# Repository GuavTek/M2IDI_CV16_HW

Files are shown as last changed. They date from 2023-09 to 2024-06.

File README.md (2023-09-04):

This eurorack module has 16 general purpose outputs which can be used for: CV, gates, envelopes, LFOs+++. 
View this project on [CADLAB.io](https://cadlab.io/project/25235) to see renders of schematics and PCBs, as well as current issues. 

<h2> A part of the M2IDI prototypes </h2>

<p>
The code for this module can be found on  
<a href="https://github.com/GuavTek/M2IDI_CV16">
			  GitHub
		  </a>
</p>

<p> 
More info on the M2IDI system can be found on the 
<a href="https://hackaday.io/project/182092-modular-midi">
			  Hackaday project page
		  </a>

</p>

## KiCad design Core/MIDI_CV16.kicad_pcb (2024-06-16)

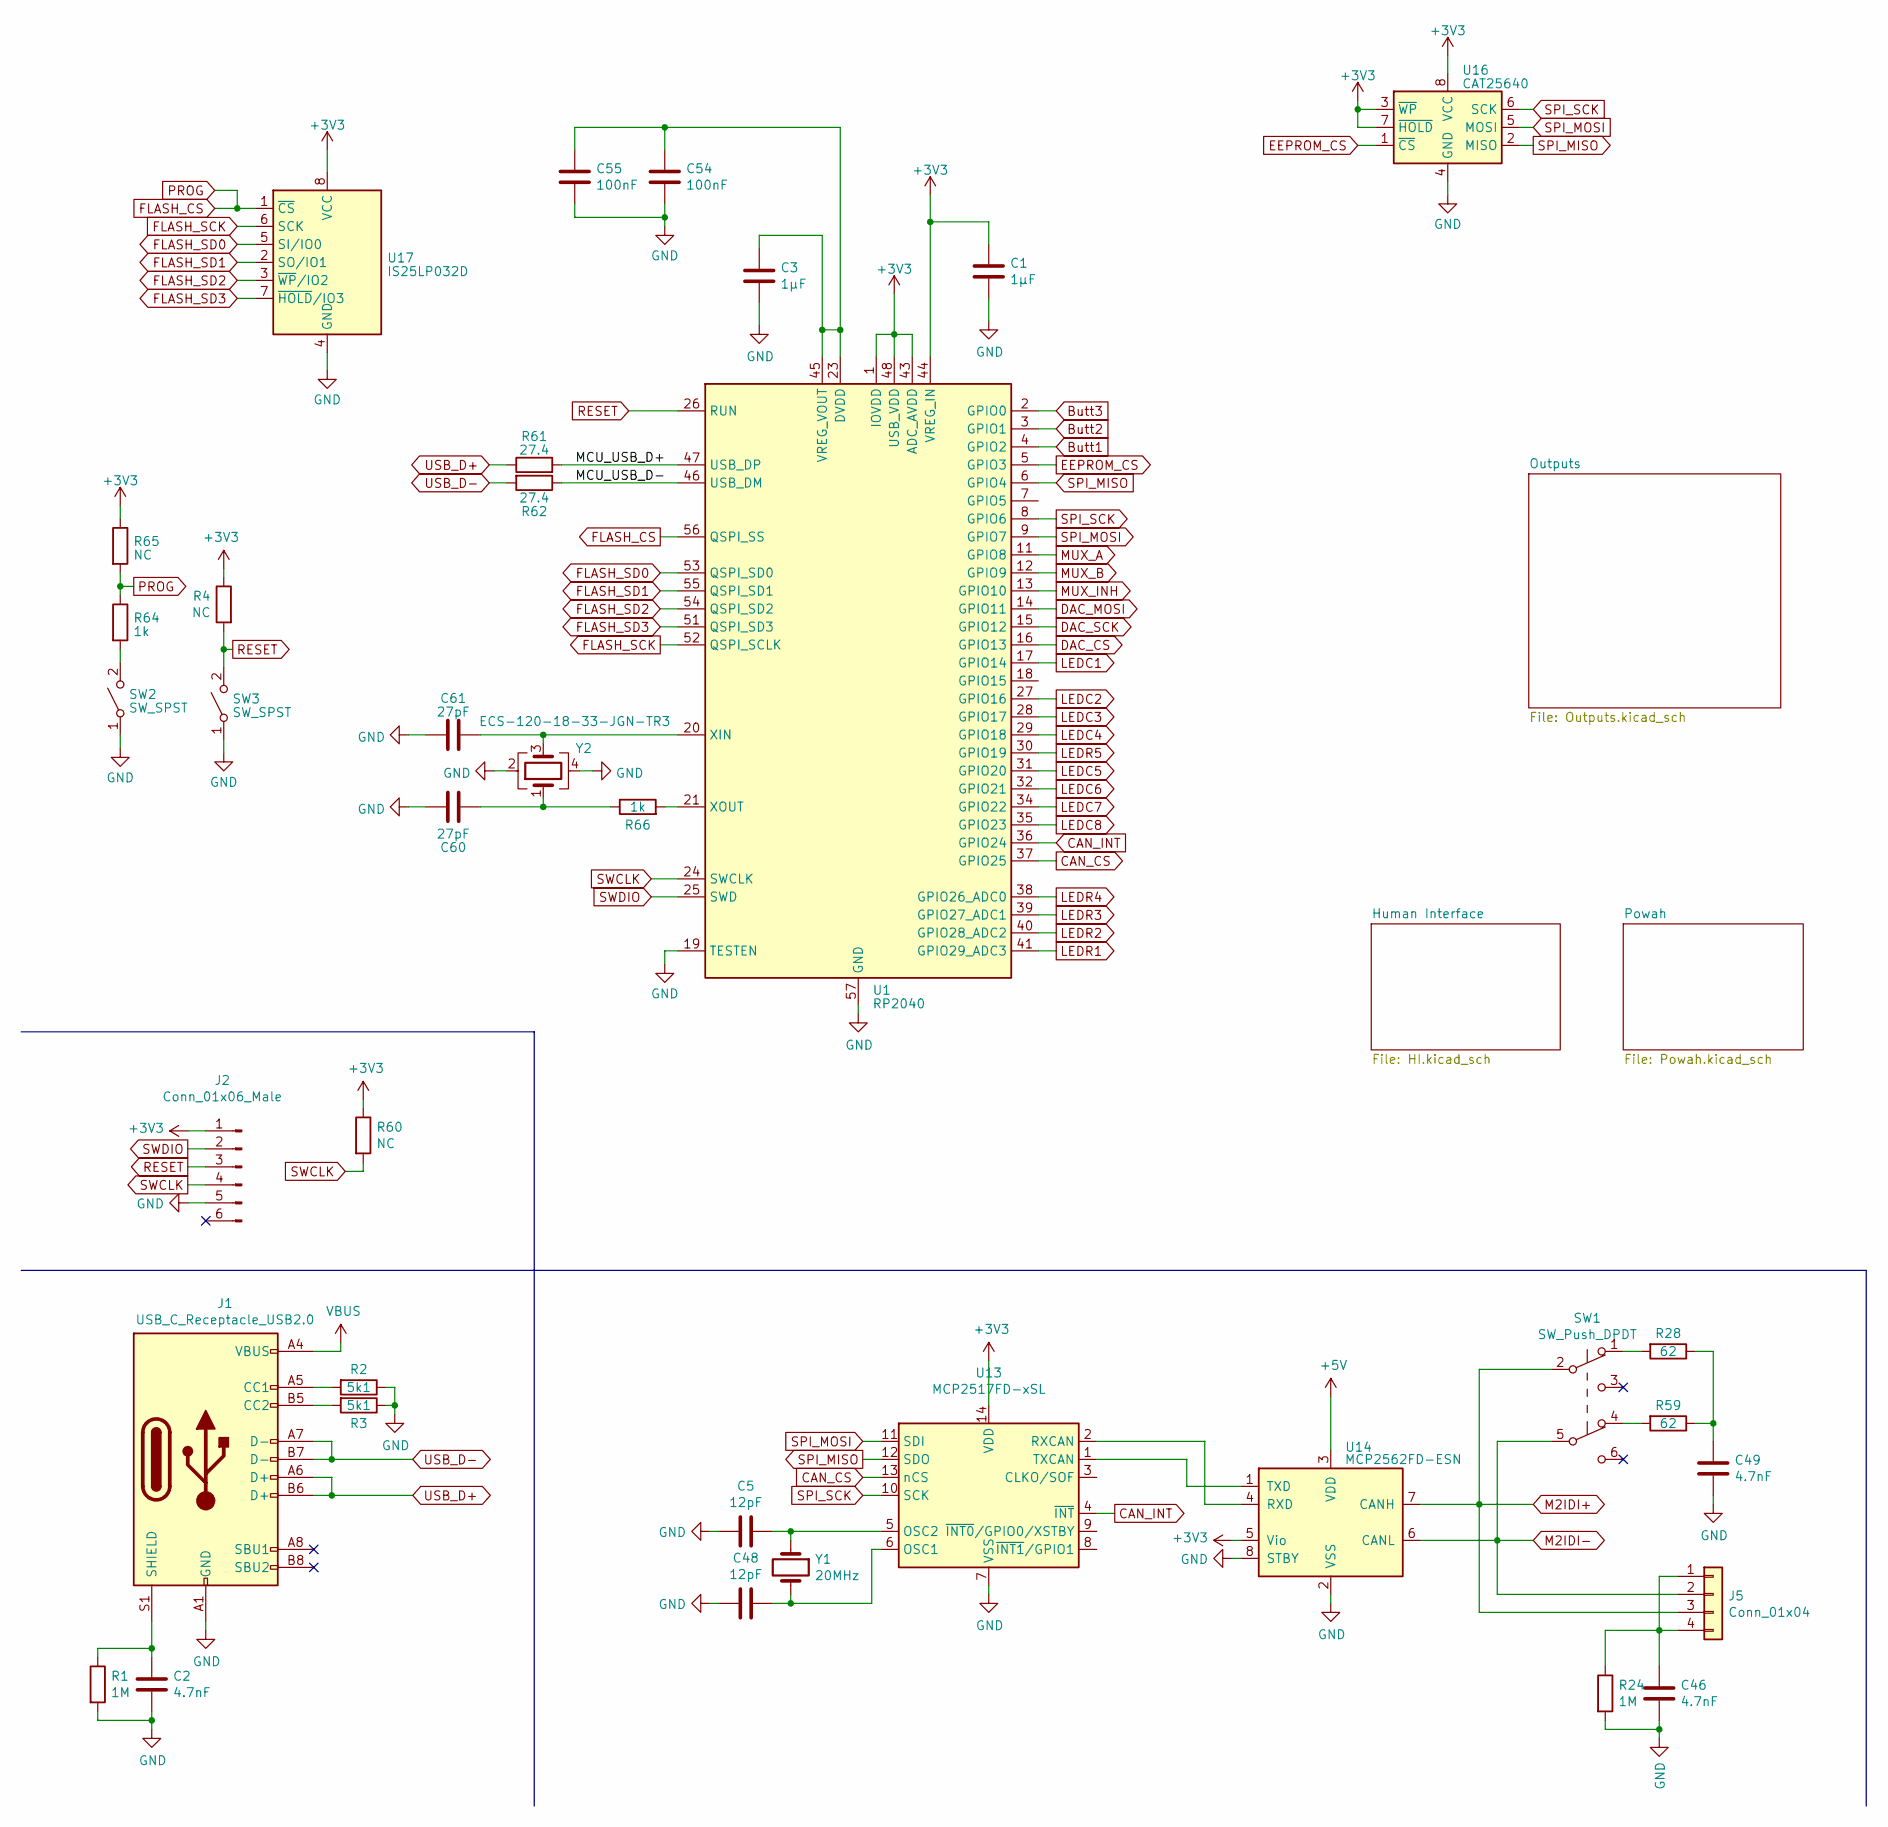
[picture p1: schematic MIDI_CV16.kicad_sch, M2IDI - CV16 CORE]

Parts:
C1, C3: 1µF; C_0603_1608Metric
C2, C46, C49: 4.7nF; C_0603_1608Metric
C5, C48: 12pF; C_0603_1608Metric
C54, C55: 100nF; C_0603_1608Metric
C60, C61: 27pF; C_0603_1608Metric
J1: USB_C_Receptacle_USB2.0; USB_C_Receptacle_HRO_TYPE-C-31-M-12
J2: Conn_01x06_Male; TSM103-DH
J5: Conn_01x04; MicroMatch_04_Vertical_SMD_Lock
R1, R24: 1M; R_0603_1608Metric
R2, R3: 5k1; R_0603_1608Metric
R4, R60, R65: NC; R_0603_1608Metric
R28, R59: 62; R_0805_2012Metric
R61, R62: 27.4; R_0603_1608Metric
R64, R66: 1k; R_0603_1608Metric
SW1: SW_Push_DPDT; SlideDPDT_JS202011
SW2, SW3: SW_SPST; Tactile_angled_SPST_5x5.4_SMD
U1: RP2040; QFN-56-1EP_7x7mm_P0.4mm_EP3.2x3.2mm
U13: MCP2517FD-xSL; SOIC-14_3.9x8.7mm_P1.27mm
U14: MCP2562FD-ESN; SOIC-8_3.9x4.9mm_P1.27mm
U16: CAT25640; SO-8_3.9x4.9mm_P1.27mm
U17: IS25LP032D; SOIC-8_3.9x4.9mm_P1.27mm
Y1: 20MHz; Crystal_2pin_2.0x2.5mm
Y2: ECS-120-18-33-JGN-TR3; Crystal_SMD_3225-4Pin_3.2x2.5mm_HandSoldering

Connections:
+3V3: C1.1, J2.1, R4.1, R60.1, R65.1, U1.1 (IOVDD), U1.10 (IOVDD), U1.22 (IOVDD), U1.33 (IOVDD), U1.42 (IOVDD), U1.43 (ADC_AVDD), U1.44 (VREG_IN), U1.48 (USB_VDD), U1.49 (IOVDD), U13.14 (VDD), U14.5 (Vio), U16.3 (~WP), U16.7 (~HOLD), U16.8 (VCC), U17.8 (VCC); also elsewhere on the board
+5V: U14.3 (VDD); also elsewhere on the board
/MCU_USB_D+: R61.2, U1.47 (USB_DP)
/MCU_USB_D-: R62.1, U1.46 (USB_DM)
Butt1: U1.4 (GPIO2); also elsewhere on the board
Butt2: U1.3 (GPIO1); also elsewhere on the board
Butt3: U1.2 (GPIO0); also elsewhere on the board
CAN_CS: U1.37 (GPIO25), U13.13 (nCS)
CAN_INT: U1.36 (GPIO24), U13.4 (~INT)
DAC_CS: U1.16 (GPIO13); also elsewhere on the board
DAC_MOSI: U1.14 (GPIO11); also elsewhere on the board
DAC_SCK: U1.15 (GPIO12); also elsewhere on the board
EEPROM_CS: U1.5 (GPIO3), U16.1 (~CS)
FLASH_CS: R64.1, R65.2, U1.56 (QSPI_SS), U17.1 (~CS)
FLASH_SCK: U1.52 (QSPI_SCLK), U17.6 (SCK)
FLASH_SD0: U1.53 (QSPI_SD0), U17.5 (SI/IO0)
FLASH_SD1: U1.55 (QSPI_SD1), U17.2 (SO/IO1)
FLASH_SD2: U1.54 (QSPI_SD2), U17.3 (~WP/IO2)
FLASH_SD3: U1.51 (QSPI_SD3), U17.7 (~HOLD/IO3)
GND: C1.2, C2.2, C3.2, C5.2, C46.2, C48.2, C49.2, C54.2, C55.2, C60.1, C61.1, J1.A1 (GND), J1.A12 (GND), J1.B1 (GND), J1.B12 (GND), J2.5, R1.2, R2.1, R3.1, R24.2, SW2.1 (A), SW3.1 (A), U1.19 (TESTEN), U1.57 (GND), U13.7 (VSS), U14.2 (VSS), U14.8 (STBY), U16.4 (GND), U17.4 (GND), Y2.2, Y2.4; also elsewhere on the board
LEDC1: U1.17 (GPIO14); also elsewhere on the board
LEDC2: U1.27 (GPIO16); also elsewhere on the board
LEDC3: U1.28 (GPIO17); also elsewhere on the board
LEDC4: U1.29 (GPIO18); also elsewhere on the board
LEDC5: U1.31 (GPIO20); also elsewhere on the board
LEDC6: U1.32 (GPIO21); also elsewhere on the board
LEDC7: U1.34 (GPIO22); also elsewhere on the board
LEDC8: U1.35 (GPIO23); also elsewhere on the board
LEDR1: U1.41 (GPIO29_ADC3); also elsewhere on the board
LEDR2: U1.40 (GPIO28_ADC2); also elsewhere on the board
LEDR3: U1.39 (GPIO27_ADC1); also elsewhere on the board
LEDR4: U1.38 (GPIO26_ADC0); also elsewhere on the board
LEDR5: U1.30 (GPIO19); also elsewhere on the board
M2IDI+: J5.3, SW1.2 (B), U14.7 (CANH)
M2IDI-: J5.2, SW1.5 (B), U14.6 (CANL)
MUX_A: U1.11 (GPIO8); also elsewhere on the board
MUX_B: U1.12 (GPIO9); also elsewhere on the board
MUX_INH: U1.13 (GPIO10); also elsewhere on the board
unnamed: C49.1, R28.1, R59.1
unnamed: C60.2, R66.1, Y2.1
unnamed: J1.A5 (CC1), R2.2
unnamed: J1.B5 (CC2), R3.2
unnamed: C2.1, J1.S1 (SHIELD), R1.1
unnamed: C46.1, J5.1, J5.4, R24.1
unnamed: R28.2, SW1.1 (A)
unnamed: R59.2, SW1.4 (A)
unnamed: R64.2, SW2.2 (B)
unnamed: C3.1, C54.1, C55.1, U1.23 (DVDD), U1.45 (VREG_VOUT), U1.50 (DVDD)
unnamed: C61.2, U1.20 (XIN), Y2.3
unnamed: R66.2, U1.21 (XOUT)
unnamed: C48.1, U13.6 (OSC1), Y1.2
unnamed: C5.1, U13.5 (OSC2), Y1.1
unnamed: U13.2 (RXCAN), U14.4 (RXD)
unnamed: U13.1 (TXCAN), U14.1 (TXD)
RESET: J2.3, R4.2, SW3.2 (B), U1.26 (RUN)
SPI_MISO: U1.6 (GPIO4), U13.12 (SDO), U16.2 (MISO)
SPI_MOSI: U1.9 (GPIO7), U13.11 (SDI), U16.5 (MOSI)
SPI_SCK: U1.8 (GPIO6), U13.10 (SCK), U16.6 (SCK)
SWCLK: J2.4, R60.2, U1.24 (SWCLK)
SWDIO: J2.2, U1.25 (SWD)
USB_D+: J1.A6 (D+), J1.B6 (D+), R61.1
USB_D-: J1.A7 (D-), J1.B7 (D-), R62.2
VBUS: J1.A4 (VBUS), J1.A9 (VBUS), J1.B4 (VBUS), J1.B9 (VBUS); also elsewhere on the board

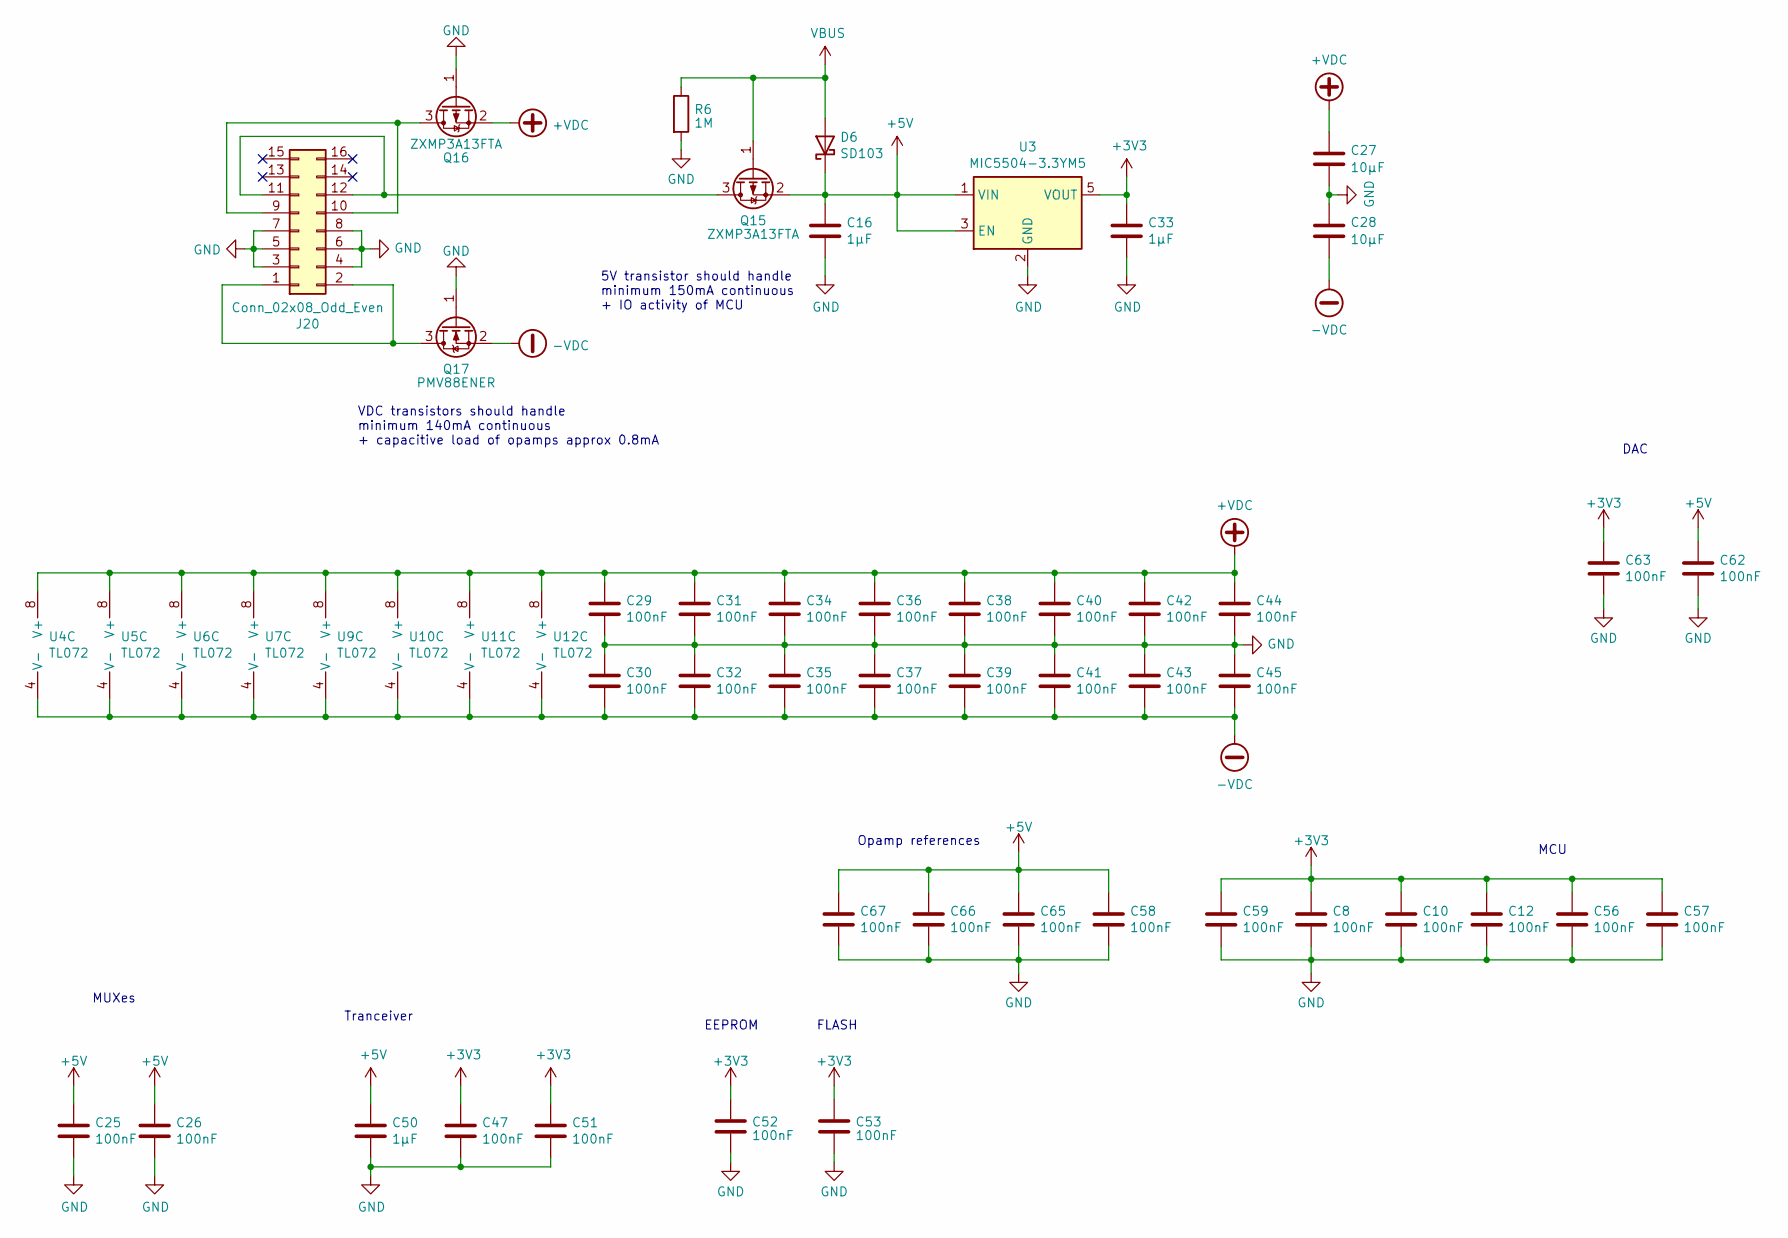
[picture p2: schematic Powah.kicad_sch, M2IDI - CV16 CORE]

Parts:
C8, C10, C12, C25, C26, C29, C30, C31, C32, C34, C35, C36, C37, C38, C39, C40, C41, C42, C43, C44, C45, C47, C51, C52, C53, C56, C57, C58, C59, C62, C63, C65, C66, C67: 100nF; C_0603_1608Metric
C16, C33, C50: 1µF; C_0603_1608Metric
C27, C28: 10µF; C_0805_2012Metric
D6: SD103; D_SOD-323_HandSoldering
J20: Conn_02x08_Odd_Even; Header_2x8_Shrouded_SMD
Q15, Q16: ZXMP3A13FTA; SOT-23
Q17: PMV88ENER; SOT-23
R6: 1M; R_0603_1608Metric
U3: MIC5504-3.3YM5; SOT-23-5
U4, U5, U6, U7, U9, U10, U11, U12: TL072; SOIC-8_3.9x4.9mm_P1.27mm

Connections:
+3V3: C8.1, C10.1, C12.1, C33.1, C47.1, C51.1, C52.1, C53.1, C56.1, C57.1, C59.1, C63.1, U3.5 (VOUT); also elsewhere on the board
+5V: C16.1, C25.1, C26.1, C50.1, C58.1, C62.1, C65.1, C66.1, C67.1, D6.1 (K), Q15.2 (S), U3.1 (VIN), U3.3 (EN); also elsewhere on the board
+VDC: C27.1, C29.1, C31.1, C34.1, C36.1, C38.1, C40.1, C42.1, C44.1, Q16.2 (S), U4.8 (V+), U5.8 (V+), U6.8 (V+), U7.8 (V+), U9.8 (V+), U10.8 (V+), U11.8 (V+), U12.8 (V+); also elsewhere on the board
-VDC: C28.2, C30.2, C32.2, C35.2, C37.2, C39.2, C41.2, C43.2, C45.2, Q17.2 (S), U4.4 (V-), U5.4 (V-), U6.4 (V-), U7.4 (V-), U9.4 (V-), U10.4 (V-), U11.4 (V-), U12.4 (V-); also elsewhere on the board
GND: C8.2, C10.2, C12.2, C16.2, C25.2, C26.2, C27.2, C28.1, C29.2, C30.1, C31.2, C32.1, C33.2, C34.2, C35.1, C36.2, C37.1, C38.2, C39.1, C40.2, C41.1, C42.2, C43.1, C44.2, C45.1, C47.2, C50.2, C51.2, C52.2, C53.2, C56.2, C57.2, C58.2, C59.2, C62.2, C63.2, C65.2, C66.2, C67.2, J20.3, J20.4, J20.5, J20.6, J20.7, J20.8, Q16.1 (G), Q17.1 (G), R6.2, U3.2 (GND); also elsewhere on the board
unnamed: J20.1, J20.2, Q17.3 (D)
unnamed: J20.9, J20.10, Q16.3 (D)
unnamed: J20.11, J20.12, Q15.3 (D)
VBUS: D6.2 (A), Q15.1 (G), R6.1; also elsewhere on the board

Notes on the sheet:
Opamp references
MUXes
EEPROM
DAC
VDC transistors should handle minimum 140mA continuous + capacitive load of opamps approx 0.8mA
Tranceiver
MCU
5V transistor should handle minimum 150mA continuous + IO activity of MCU
FLASH

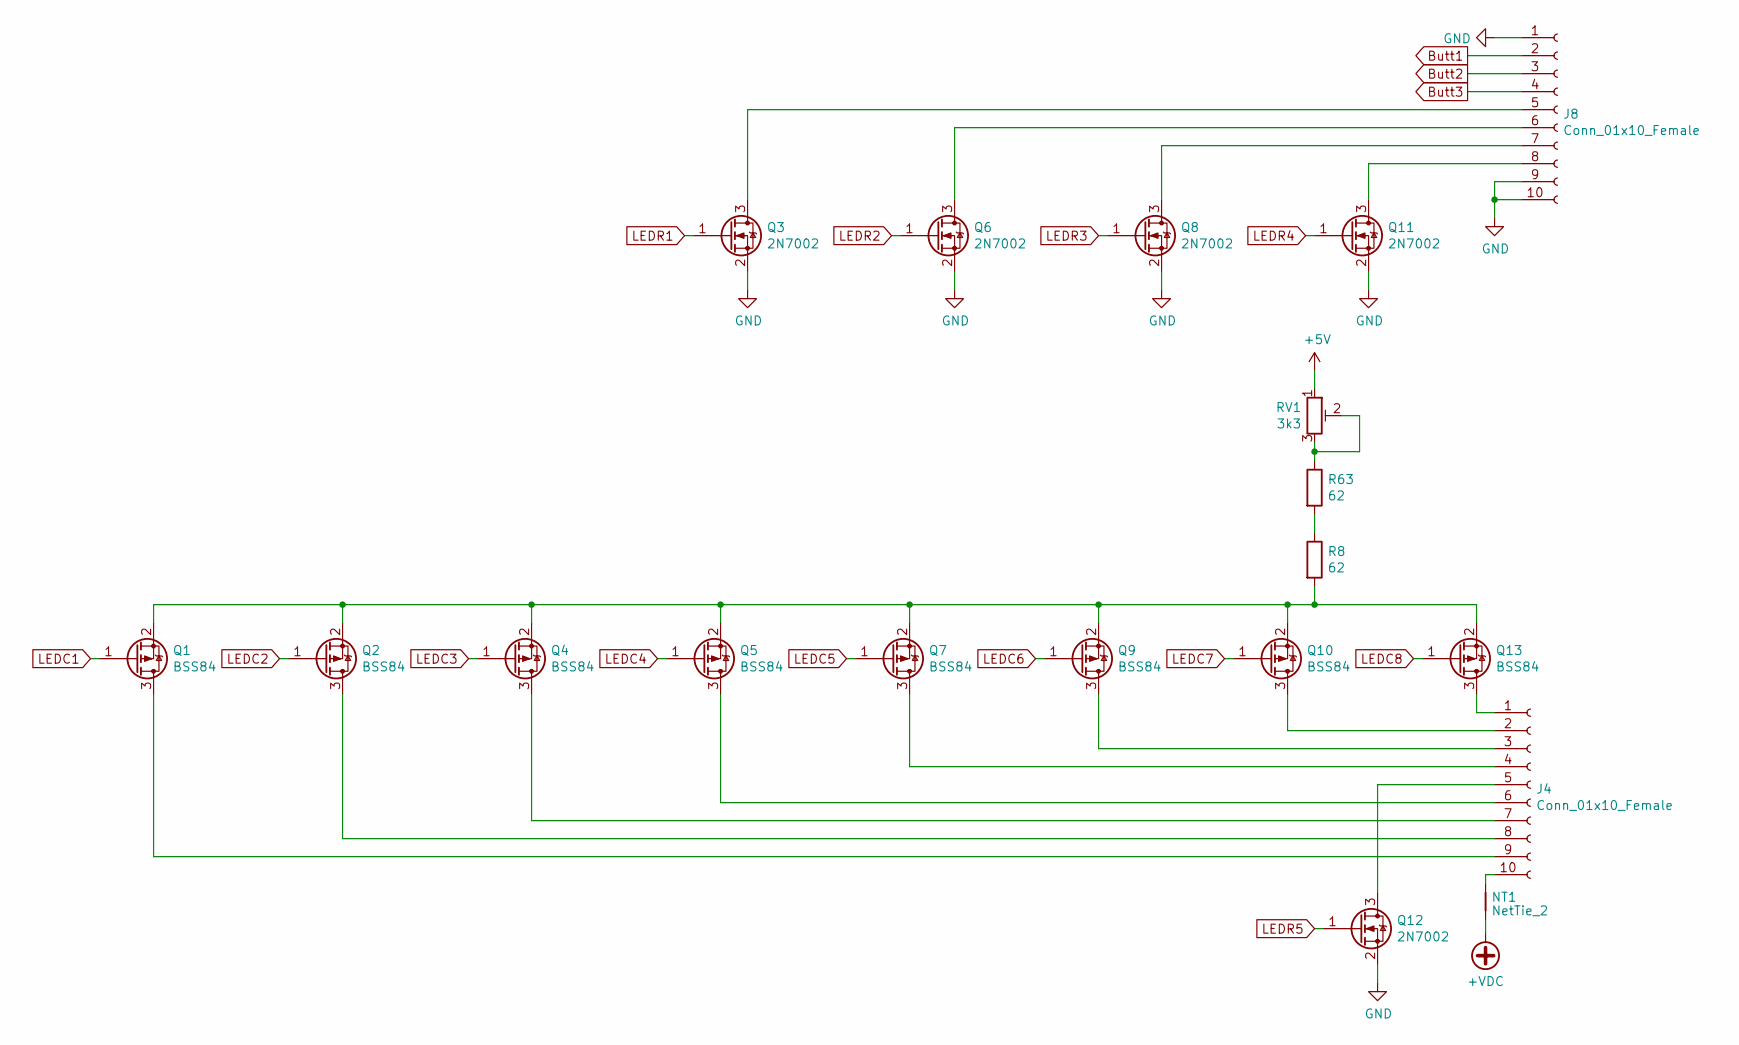
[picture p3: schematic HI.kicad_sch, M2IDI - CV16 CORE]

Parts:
J4, J8: Conn_01x10_Female; PinSocket_1x10_P2.54mm_Vertical_SMD_Pin1Both
NT1: NetTie_2; NetTie_NC0603
Q1, Q2, Q4, Q5, Q7, Q9, Q10, Q13: BSS84; SOT-23
Q3, Q6, Q8, Q11, Q12: 2N7002; SOT-23
R8, R63: 62; R_0805_2012Metric
RV1: 3k3; VG039N

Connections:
+5V: RV1.1; also elsewhere on the board
+VDC: NT1.1; also elsewhere on the board
Butt1: J8.2; also elsewhere on the board
Butt2: J8.3; also elsewhere on the board
Butt3: J8.4; also elsewhere on the board
GND: J8.1, J8.9, J8.10, Q3.2 (S), Q6.2 (S), Q8.2 (S), Q11.2 (S), Q12.2 (S); also elsewhere on the board
LEDC1: Q1.1 (G); also elsewhere on the board
LEDC2: Q2.1 (G); also elsewhere on the board
LEDC3: Q4.1 (G); also elsewhere on the board
LEDC4: Q5.1 (G); also elsewhere on the board
LEDC5: Q7.1 (G); also elsewhere on the board
LEDC6: Q9.1 (G); also elsewhere on the board
LEDC7: Q10.1 (G); also elsewhere on the board
LEDC8: Q13.1 (G); also elsewhere on the board
LEDR1: Q3.1 (G); also elsewhere on the board
LEDR2: Q6.1 (G); also elsewhere on the board
LEDR3: Q8.1 (G); also elsewhere on the board
LEDR4: Q11.1 (G); also elsewhere on the board
LEDR5: Q12.1 (G); also elsewhere on the board
unnamed: J4.1, Q13.3 (D)
unnamed: J4.2, Q10.3 (D)
unnamed: J4.3, Q9.3 (D)
unnamed: J4.4, Q7.3 (D)
unnamed: J4.5, Q12.3 (D)
unnamed: J4.6, Q5.3 (D)
unnamed: J4.7, Q4.3 (D)
unnamed: J4.8, Q2.3 (D)
unnamed: J4.9, Q1.3 (D)
unnamed: J4.10, NT1.2
unnamed: J8.5, Q3.3 (D)
unnamed: J8.6, Q6.3 (D)
unnamed: J8.7, Q8.3 (D)
unnamed: J8.8, Q11.3 (D)
unnamed: Q1.2 (S), Q2.2 (S), Q4.2 (S), Q5.2 (S), Q7.2 (S), Q9.2 (S), Q10.2 (S), Q13.2 (S), R8.2
unnamed: R63.1, RV1.2, RV1.3
unnamed: R8.1, R63.2

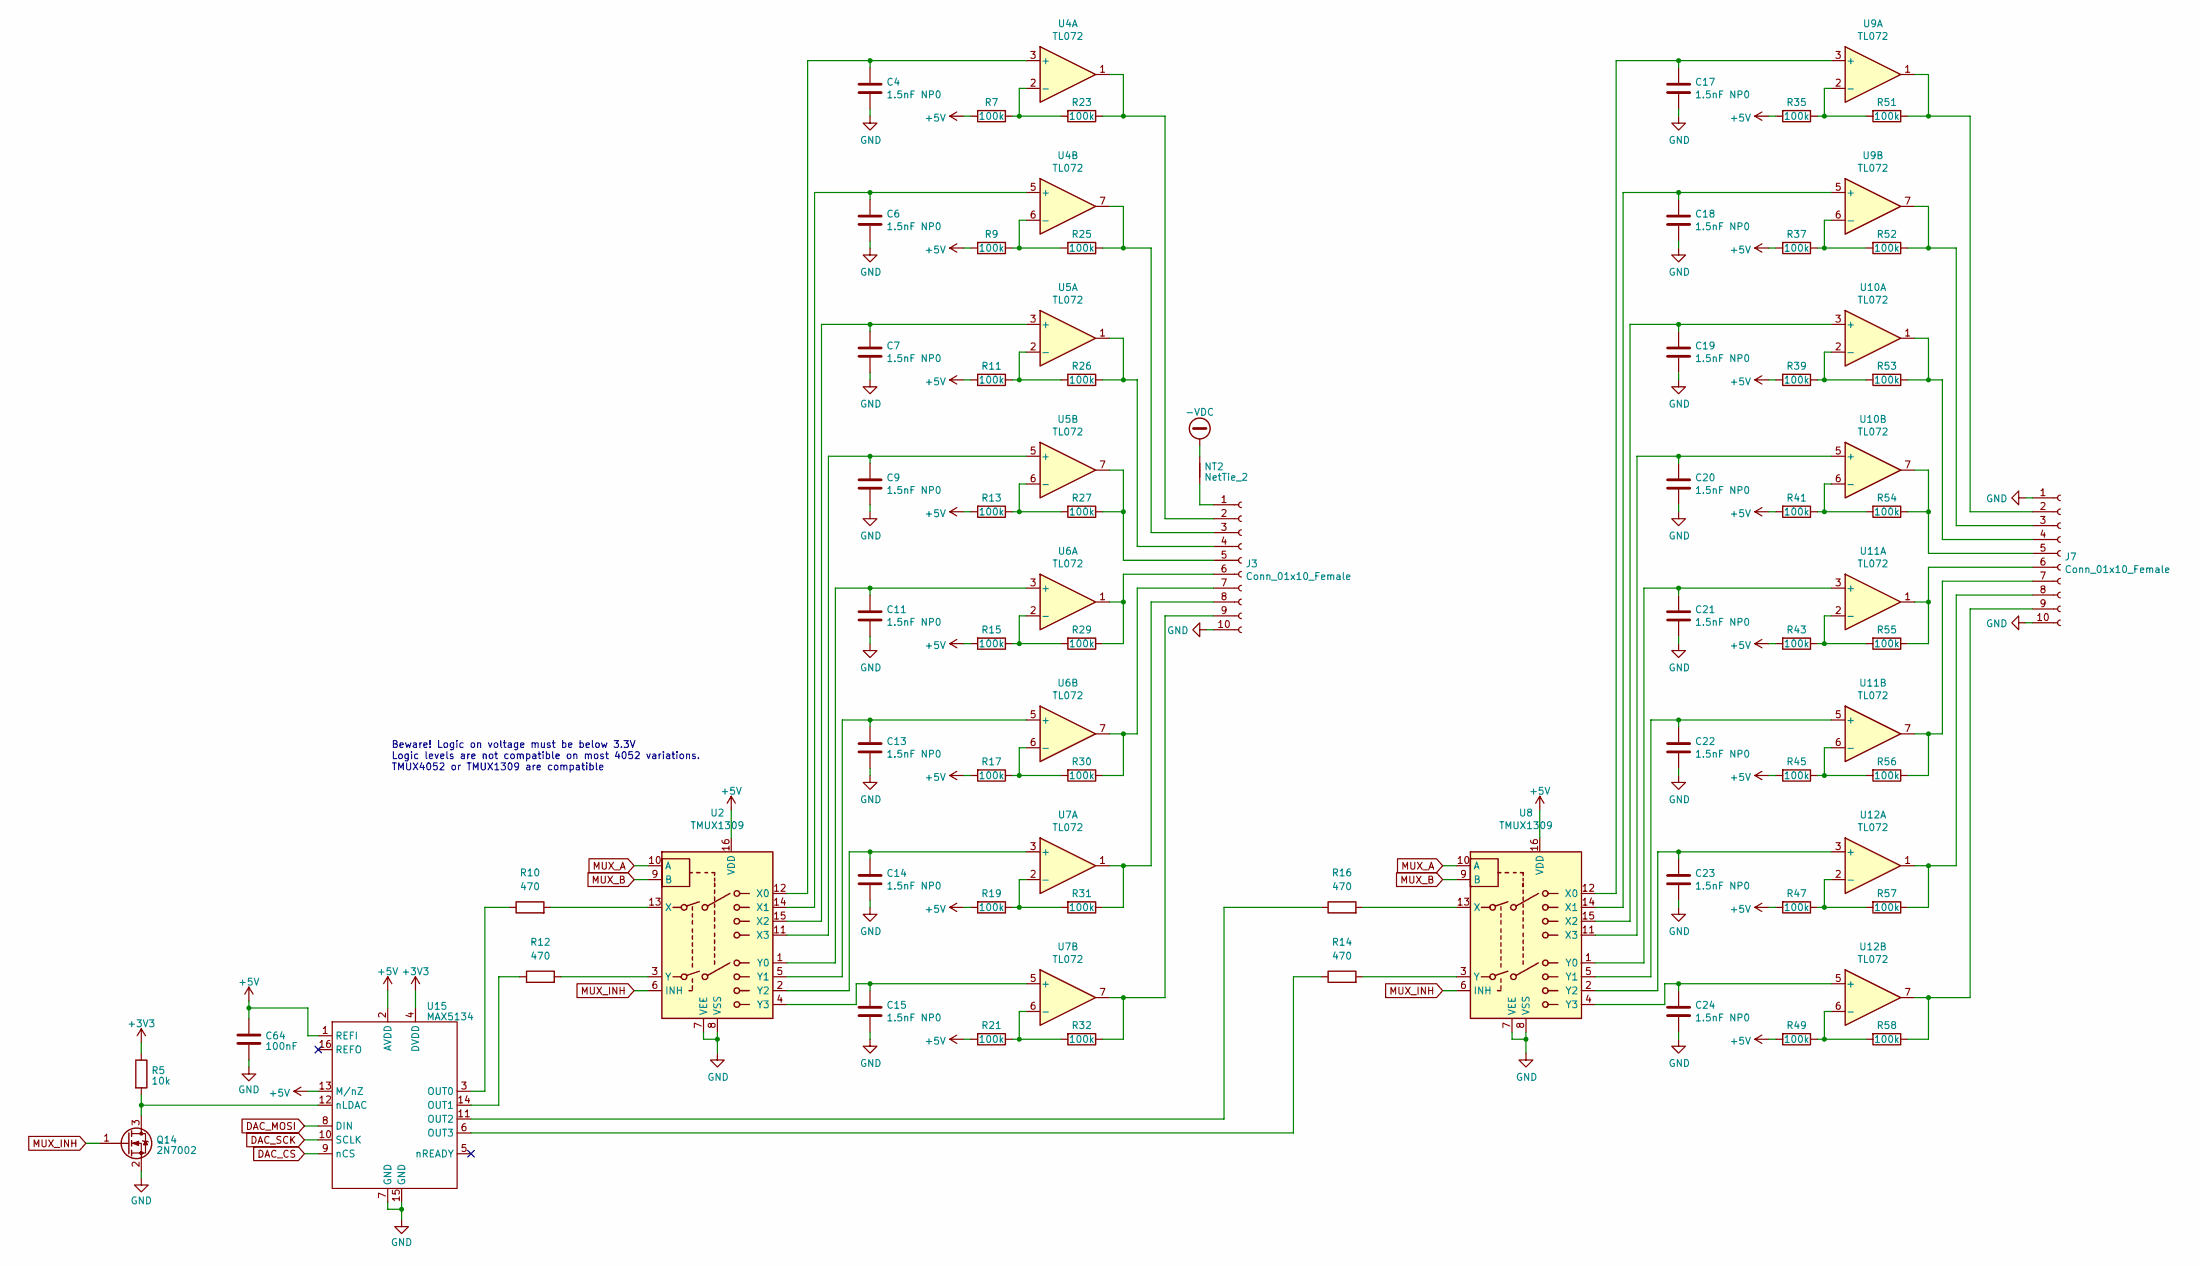
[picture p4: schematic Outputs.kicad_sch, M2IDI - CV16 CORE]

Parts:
C4, C6, C7, C9, C11, C13, C14, C15, C17, C18, C19, C20, C21, C22, C23, C24: 1.5nF NP0; C_0603_1608Metric
C64: 100nF; C_0603_1608Metric
J3, J7: Conn_01x10_Female; PinSocket_1x10_P2.54mm_Vertical_SMD_Pin1Both
NT2: NetTie_2; NetTie_NC0603
Q14: 2N7002; SOT-23
R5: 10k; R_0603_1608Metric
R7, R9, R11, R13, R15, R17, R19, R21, R23, R25, R26, R27, R29, R30, R31, R32, R35, R37, R39, R41, R43, R45, R47, R49, R51, R52, R53, R54, R55, R56, R57, R58: 100k; R_0603_1608Metric
R10, R12, R14, R16: 470; R_0603_1608Metric
U2, U8: TMUX1309; TSSOP-16_4.4x5mm_P0.65mm
U4, U5, U6, U7, U9, U10, U11, U12: TL072; SOIC-8_3.9x4.9mm_P1.27mm
U15: MAX5134; TSSOP-16_4.4x5mm_P0.65mm

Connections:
+3V3: R5.1, U15.4 (DVDD); also elsewhere on the board
+5V: C64.1, R7.2, R9.2, R11.2, R13.2, R15.2, R17.2, R19.2, R21.2, R35.2, R37.2, R39.2, R41.2, R43.2, R45.2, R47.2, R49.2, U2.16 (VDD), U8.16 (VDD), U15.1 (REFI), U15.2 (AVDD), U15.13 (M/nZ); also elsewhere on the board
-VDC: NT2.2; also elsewhere on the board
DAC_CS: U15.9 (nCS); also elsewhere on the board
DAC_MOSI: U15.8 (DIN); also elsewhere on the board
DAC_SCK: U15.10 (SCLK); also elsewhere on the board
GND: C4.2, C6.2, C7.2, C9.2, C11.2, C13.2, C14.2, C15.2, C17.2, C18.2, C19.2, C20.2, C21.2, C22.2, C23.2, C24.2, C64.2, J3.10, J7.1, J7.10, Q14.2 (S), U2.7 (VEE), U2.8 (VSS), U8.7 (VEE), U8.8 (VSS), U15.7 (GND), U15.15 (GND); also elsewhere on the board
MUX_A: U2.10 (A), U8.10 (A); also elsewhere on the board
MUX_B: U2.9 (B), U8.9 (B); also elsewhere on the board
MUX_INH: Q14.1 (G), U2.6 (INH), U8.6 (INH); also elsewhere on the board
unnamed: J3.1, NT2.1
unnamed: J3.2, R23.1, U4.1
unnamed: J3.3, R25.1, U4.7
unnamed: J3.4, R26.1, U5.1
unnamed: J3.5, R27.1, U5.7
unnamed: J3.6, R29.1, U6.1
unnamed: J3.7, R30.1, U6.7
unnamed: J3.8, R31.1, U7.1
unnamed: J3.9, R32.1, U7.7
unnamed: J7.2, R51.1, U9.1
unnamed: J7.3, R52.1, U9.7
unnamed: J7.4, R53.1, U10.1
unnamed: J7.5, R54.1, U10.7
unnamed: J7.6, R55.1, U11.1
unnamed: J7.7, R56.1, U11.7
unnamed: J7.8, R57.1, U12.1
unnamed: J7.9, R58.1, U12.7
unnamed: Q14.3 (D), R5.2, U15.12 (nLDAC)
unnamed: C4.1, U2.12 (X0), U4.3 (+)
unnamed: C6.1, U2.14 (X1), U4.5 (+)
unnamed: C7.1, U2.15 (X2), U5.3 (+)
unnamed: C9.1, U2.11 (X3), U5.5 (+)
unnamed: R10.2, U2.13 (X)
unnamed: C11.1, U2.1 (Y0), U6.3 (+)
unnamed: C13.1, U2.5 (Y1), U6.5 (+)
unnamed: C14.1, U2.2 (Y2), U7.3 (+)
unnamed: C15.1, U2.4 (Y3), U7.5 (+)
unnamed: R12.2, U2.3 (Y)
unnamed: R7.1, R23.2, U4.2 (-)
unnamed: R9.1, R25.2, U4.6 (-)
unnamed: R11.1, R26.2, U5.2 (-)
unnamed: R13.1, R27.2, U5.6 (-)
unnamed: R15.1, R29.2, U6.2 (-)
unnamed: R17.1, R30.2, U6.6 (-)
unnamed: R19.1, R31.2, U7.2 (-)
unnamed: R21.1, R32.2, U7.6 (-)
unnamed: C17.1, U8.12 (X0), U9.3 (+)
unnamed: C18.1, U8.14 (X1), U9.5 (+)
unnamed: R16.2, U8.13 (X)
unnamed: R14.2, U8.3 (Y)
unnamed: R35.1, R51.2, U9.2 (-)
unnamed: R37.1, R52.2, U9.6 (-)
unnamed: C19.1, U8.15 (X2), U10.3 (+)
unnamed: R39.1, R53.2, U10.2 (-)
unnamed: C20.1, U8.11 (X3), U10.5 (+)
unnamed: R41.1, R54.2, U10.6 (-)
unnamed: C21.1, U8.1 (Y0), U11.3 (+)
unnamed: R43.1, R55.2, U11.2 (-)
unnamed: C22.1, U8.5 (Y1), U11.5 (+)
unnamed: R45.1, R56.2, U11.6 (-)
unnamed: C23.1, U8.2 (Y2), U12.3 (+)
unnamed: R47.1, R57.2, U12.2 (-)
unnamed: C24.1, U8.4 (Y3), U12.5 (+)
unnamed: R49.1, R58.2, U12.6 (-)
unnamed: R10.1, U15.3 (OUT0)
unnamed: R12.1, U15.14 (OUT1)
unnamed: R16.1, U15.11 (OUT2)
unnamed: R14.1, U15.6 (OUT3)

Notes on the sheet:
Beware! Logic on voltage must be below 3.3V Logic levels are not compatible on most 4052 variations. TMUX4052 or TMUX1309 are compatible

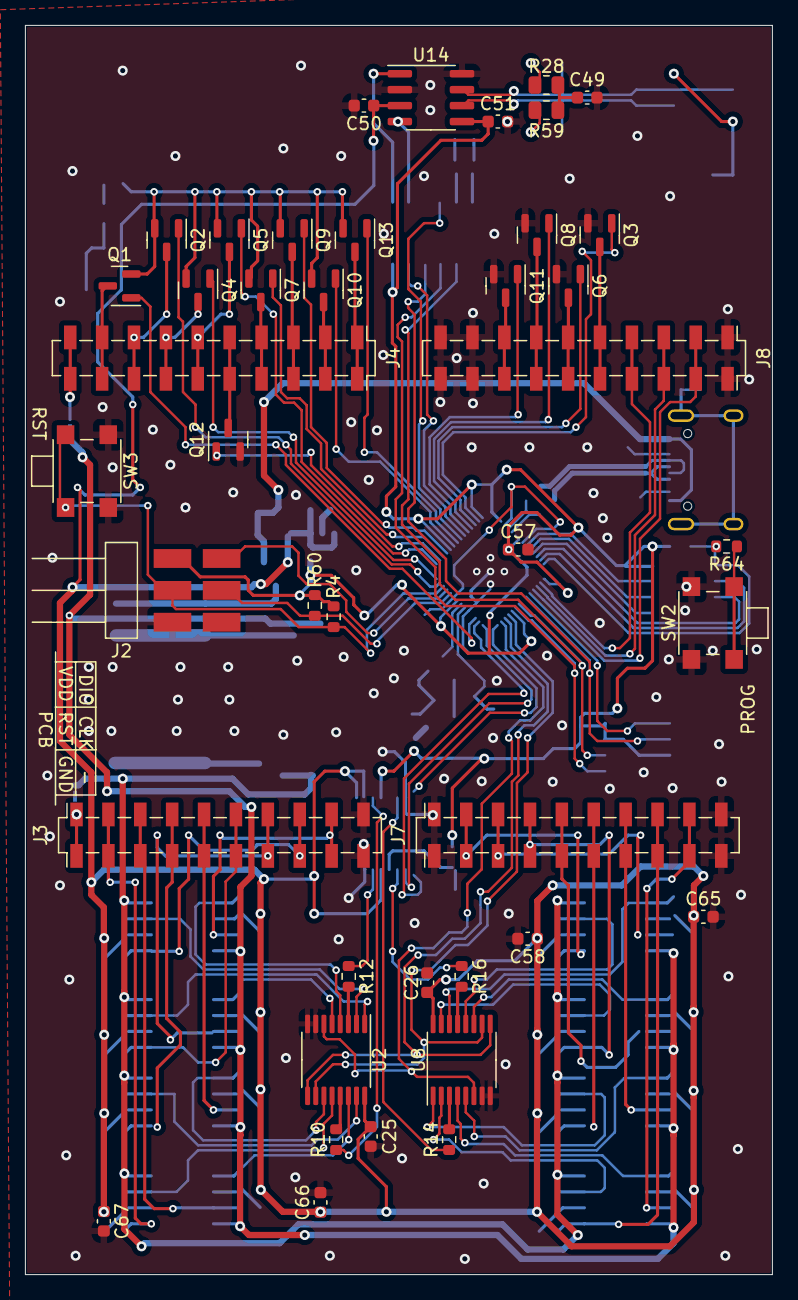
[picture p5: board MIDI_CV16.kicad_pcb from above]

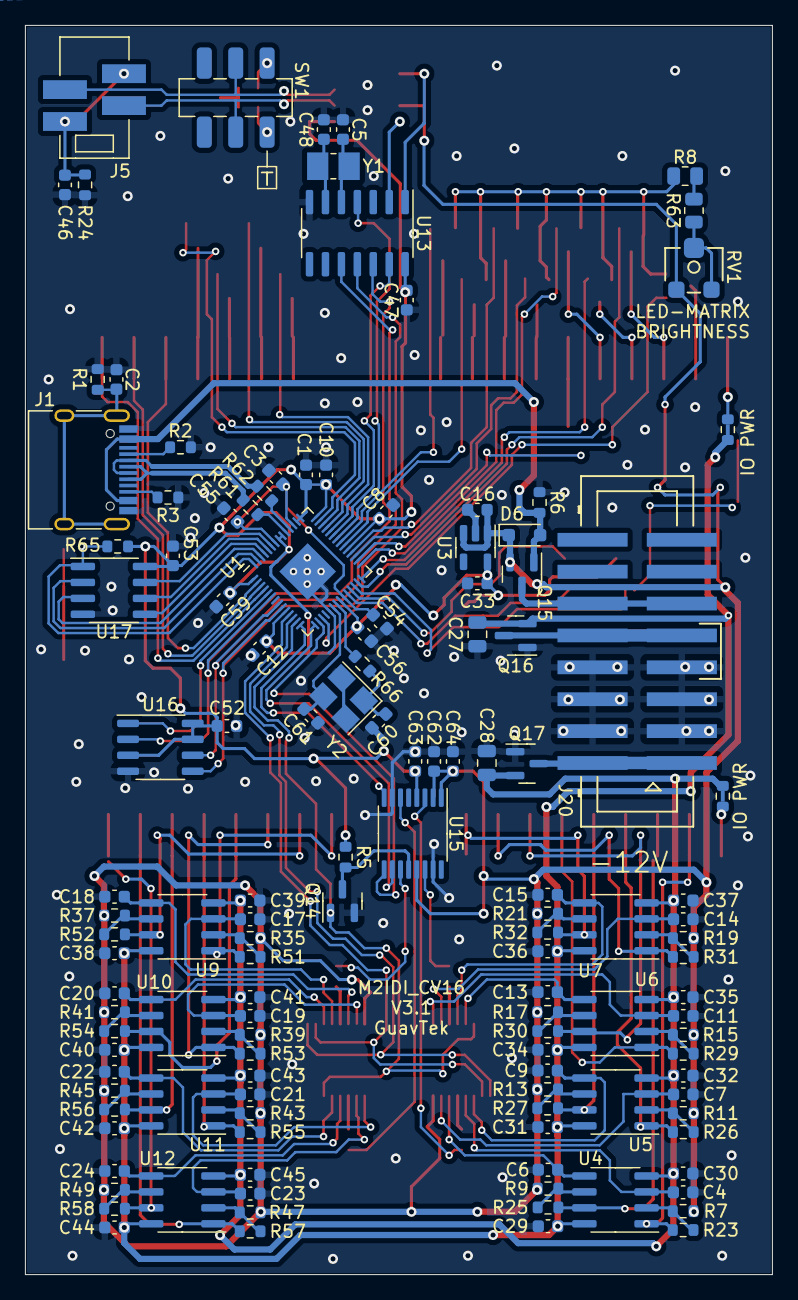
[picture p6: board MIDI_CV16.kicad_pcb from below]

Board: 2 copper layers, 59.5 x 99.5 mm, 171 parts (129 on the bottom side), 143 nets.

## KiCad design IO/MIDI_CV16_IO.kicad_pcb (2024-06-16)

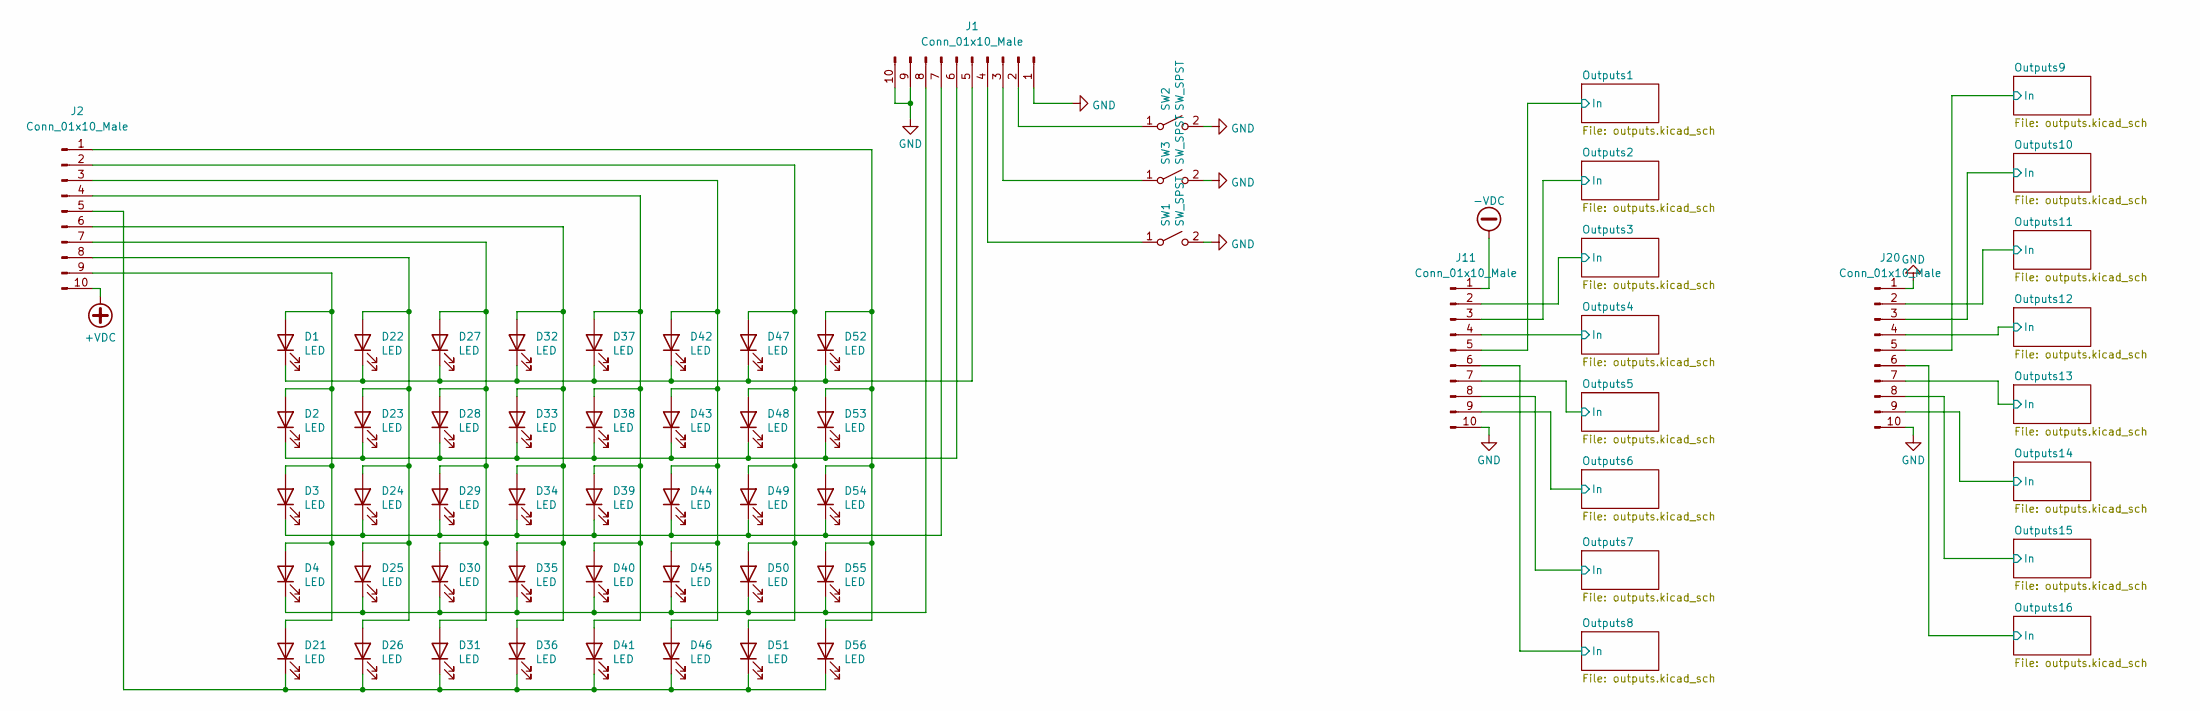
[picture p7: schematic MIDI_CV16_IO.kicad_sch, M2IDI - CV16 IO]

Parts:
D1, D2, D3, D4, D21, D22, D23, D24, D25, D26, D27, D28, D29, D30, D31, D32, D33, D34, D35, D36, D37, D38, D39, D40, D41, D42, D43, D44, D45, D46, D47, D48, D49, D50, D51, D52, D53, D54, D55, D56: LED; LED_D3.0mm_NoCourtyard
J1, J2, J11, J20: Conn_01x10_Male; PinHeader_1x10_P2.54mm_Vertical_SMD_Pin1Right
SW1, SW2, SW3: SW_SPST; SW_PUSH_6mm_H13mm

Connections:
+VDC: J2.10; also elsewhere on the board
-VDC: J11.1; also elsewhere on the board
/Outputs1/In: J11.5; also elsewhere on the board
/Outputs2/In: J11.3; also elsewhere on the board
/Outputs3/In: J11.2; also elsewhere on the board
/Outputs4/In: J11.4; also elsewhere on the board
/Outputs5/In: J11.7; also elsewhere on the board
/Outputs6/In: J11.9; also elsewhere on the board
/Outputs7/In: J11.8; also elsewhere on the board
/Outputs8/In: J11.6; also elsewhere on the board
/Outputs9/In: J20.5; also elsewhere on the board
/Outputs10/In: J20.3; also elsewhere on the board
/Outputs11/In: J20.2; also elsewhere on the board
/Outputs12/In: J20.4; also elsewhere on the board
/Outputs13/In: J20.7; also elsewhere on the board
/Outputs14/In: J20.9; also elsewhere on the board
/Outputs15/In: J20.8; also elsewhere on the board
/Outputs16/In: J20.6; also elsewhere on the board
GND: J1.1, J1.9, J1.10, J11.10, J20.1, J20.10, SW1.2 (B), SW2.2 (B), SW3.2 (B); also elsewhere on the board
unnamed: D1.2 (A), D2.2 (A), D3.2 (A), D4.2 (A), D21.2 (A), J2.9
unnamed: D1.1 (K), D22.1 (K), D27.1 (K), D32.1 (K), D37.1 (K), D42.1 (K), D47.1 (K), D52.1 (K), J1.5
unnamed: D2.1 (K), D23.1 (K), D28.1 (K), D33.1 (K), D38.1 (K), D43.1 (K), D48.1 (K), D53.1 (K), J1.6
unnamed: D21.1 (K), D26.1 (K), D31.1 (K), D36.1 (K), D41.1 (K), D46.1 (K), D51.1 (K), D56.1 (K), J2.5
unnamed: D22.2 (A), D23.2 (A), D24.2 (A), D25.2 (A), D26.2 (A), J2.8
unnamed: D3.1 (K), D24.1 (K), D29.1 (K), D34.1 (K), D39.1 (K), D44.1 (K), D49.1 (K), D54.1 (K), J1.7
unnamed: D4.1 (K), D25.1 (K), D30.1 (K), D35.1 (K), D40.1 (K), D45.1 (K), D50.1 (K), D55.1 (K), J1.8
unnamed: D27.2 (A), D28.2 (A), D29.2 (A), D30.2 (A), D31.2 (A), J2.7
unnamed: D32.2 (A), D33.2 (A), D34.2 (A), D35.2 (A), D36.2 (A), J2.6
unnamed: D37.2 (A), D38.2 (A), D39.2 (A), D40.2 (A), D41.2 (A), J2.4
unnamed: D42.2 (A), D43.2 (A), D44.2 (A), D45.2 (A), D46.2 (A), J2.3
unnamed: D47.2 (A), D48.2 (A), D49.2 (A), D50.2 (A), D51.2 (A), J2.2
unnamed: D52.2 (A), D53.2 (A), D54.2 (A), D55.2 (A), D56.2 (A), J2.1
unnamed: J1.2, SW2.1 (A)
unnamed: J1.3, SW3.1 (A)
unnamed: J1.4, SW1.1 (A)

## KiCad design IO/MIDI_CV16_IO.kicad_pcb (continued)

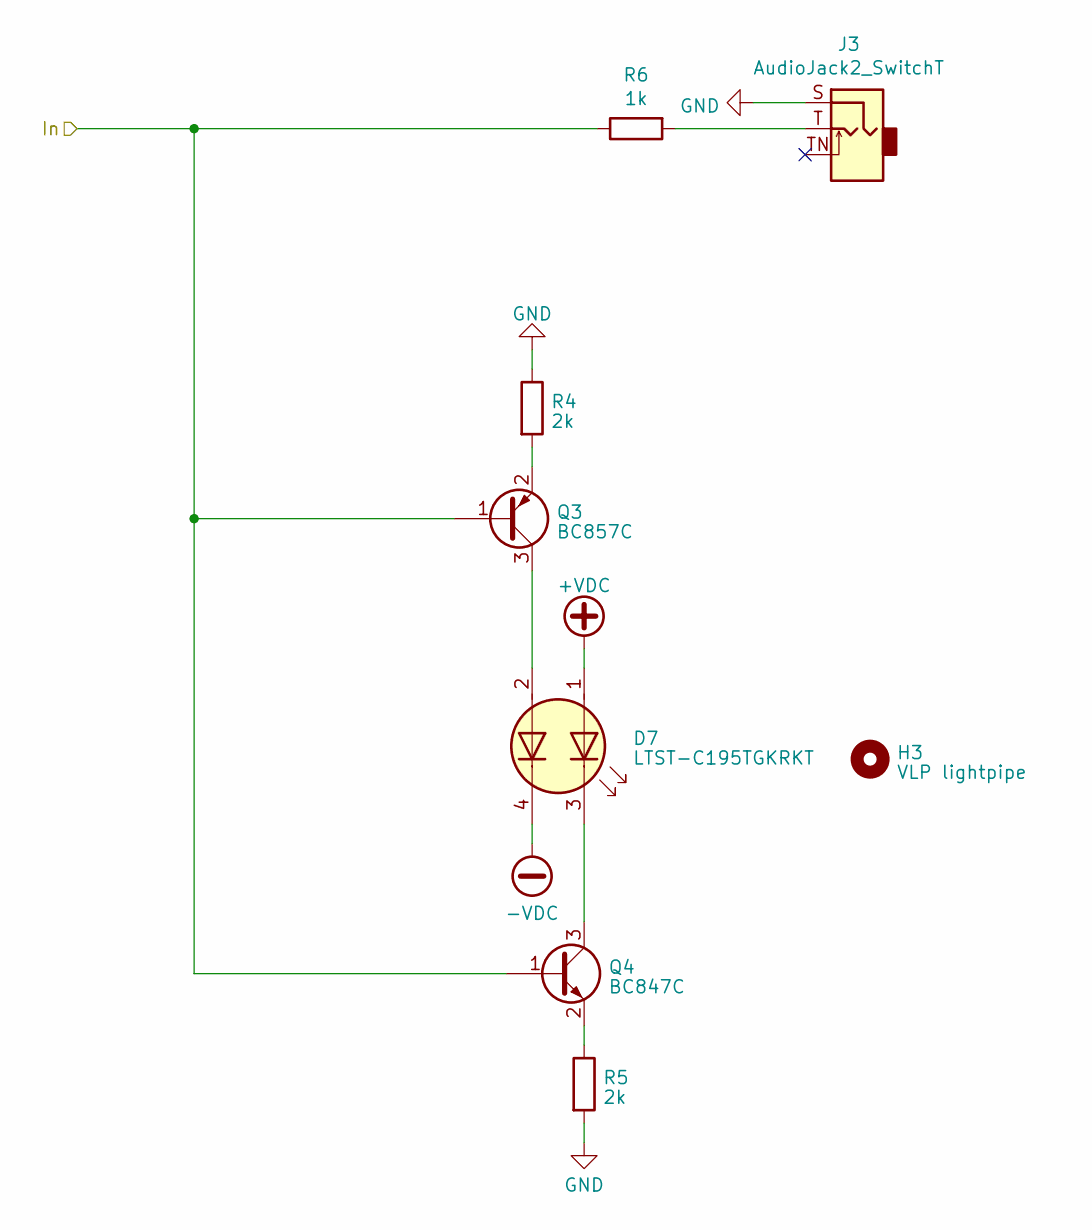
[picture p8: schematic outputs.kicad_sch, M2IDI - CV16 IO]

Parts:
D7: LTST-C195TGKRKT; LED_LiteOn_LTST-C195TGKRKT
H3: VLP lightpipe; VLP-LightPipes
J3: AudioJack2_SwitchT; PJ398SM
Q3: BC857C; SOT-23
Q4: BC847C; SOT-23
R4, R5: 2k; R_0603_1608Metric
R6: 1k; R_0603_1608Metric

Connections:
+VDC: D7.1 (A1); also elsewhere on the board
-VDC: D7.4 (K2); also elsewhere on the board
/Outputs1/In: Q3.1 (B), Q4.1 (B), R6.1; also elsewhere on the board
GND: J3.S, R4.1, R5.2; also elsewhere on the board
unnamed: D7.2 (A2), Q3.3 (C)
unnamed: D7.3 (K1), Q4.3 (C)
unnamed: J3.T, R6.2
unnamed: Q3.2 (E), R4.2
unnamed: Q4.2 (E), R5.1

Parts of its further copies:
D10, D13, D16, D19, D61, D64, D67, D70, D73, D76, D79, D82, D85, D88, D91: LTST-C195TGKRKT; LED_LiteOn_LTST-C195TGKRKT
H1, H2, H4, H5, H6, H7, H8, H9, H10, H11, H12, H13, H14, H15, H16: VLP lightpipe; VLP-LightPipes
J4, J5, J6, J7, J8, J9, J10, J12, J13, J14, J15, J16, J17, J18, J19: AudioJack2_SwitchT; PJ398SM
Q5, Q7, Q9, Q11, Q13, Q15, Q17, Q19, Q21, Q23, Q25, Q27, Q29, Q31, Q33: BC857C; SOT-23
Q6, Q8, Q10, Q12, Q14, Q16, Q18, Q20, Q22, Q24, Q26, Q28, Q30, Q32, Q34: BC847C; SOT-23
R7, R8, R10, R11, R13, R14, R16, R17, R19, R20, R22, R23, R25, R26, R28, R29, R31, R32, R34, R35, R37, R38, R40, R41, R43, R44, R46, R47, R49, R50: 2k; R_0603_1608Metric
R9, R12, R15, R18, R21, R24, R27, R30, R33, R36, R39, R42, R45, R48, R51: 1k; R_0603_1608Metric

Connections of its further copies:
+VDC: D10.1 (A1), D13.1 (A1), D16.1 (A1), D19.1 (A1), D61.1 (A1), D64.1 (A1), D67.1 (A1), D70.1 (A1), D73.1 (A1), D76.1 (A1), D79.1 (A1), D82.1 (A1), D85.1 (A1), D88.1 (A1), D91.1 (A1); also elsewhere on the board
-VDC: D10.4 (K2), D13.4 (K2), D16.4 (K2), D19.4 (K2), D61.4 (K2), D64.4 (K2), D67.4 (K2), D70.4 (K2), D73.4 (K2), D76.4 (K2), D79.4 (K2), D82.4 (K2), D85.4 (K2), D88.4 (K2), D91.4 (K2); also elsewhere on the board
/Outputs2/In: Q5.1 (B), Q6.1 (B), R9.1; also elsewhere on the board
/Outputs3/In: Q7.1 (B), Q8.1 (B), R12.1; also elsewhere on the board
/Outputs4/In: Q9.1 (B), Q10.1 (B), R15.1; also elsewhere on the board
/Outputs5/In: Q11.1 (B), Q12.1 (B), R18.1; also elsewhere on the board
/Outputs6/In: Q13.1 (B), Q14.1 (B), R21.1; also elsewhere on the board
/Outputs7/In: Q15.1 (B), Q16.1 (B), R24.1; also elsewhere on the board
/Outputs8/In: Q17.1 (B), Q18.1 (B), R27.1; also elsewhere on the board
/Outputs9/In: Q19.1 (B), Q20.1 (B), R30.1; also elsewhere on the board
/Outputs10/In: Q21.1 (B), Q22.1 (B), R33.1; also elsewhere on the board
/Outputs11/In: Q23.1 (B), Q24.1 (B), R36.1; also elsewhere on the board
/Outputs12/In: Q25.1 (B), Q26.1 (B), R39.1; also elsewhere on the board
/Outputs13/In: Q27.1 (B), Q28.1 (B), R42.1; also elsewhere on the board
/Outputs14/In: Q29.1 (B), Q30.1 (B), R45.1; also elsewhere on the board
/Outputs15/In: Q31.1 (B), Q32.1 (B), R48.1; also elsewhere on the board
/Outputs16/In: Q33.1 (B), Q34.1 (B), R51.1; also elsewhere on the board
GND: J4.S, J5.S, J6.S, J7.S, J8.S, J9.S, J10.S, J12.S, J13.S, J14.S, J15.S, J16.S, J17.S, J18.S, J19.S, R7.1, R8.2, R10.1, R11.2, R13.1, R14.2, R16.1, R17.2, R19.1, R20.2, R22.1, R23.2, R25.1, R26.2, R28.1, R29.2, R31.1, R32.2, R34.1, R35.2, R37.1, R38.2, R40.1, R41.2, R43.1, R44.2, R46.1, R47.2, R49.1, R50.2; also elsewhere on the board
unnamed: D10.2 (A2), Q5.3 (C)
unnamed: D10.3 (K1), Q6.3 (C)
unnamed: D13.2 (A2), Q7.3 (C)
unnamed: D13.3 (K1), Q8.3 (C)
unnamed: D16.2 (A2), Q9.3 (C)
unnamed: D16.3 (K1), Q10.3 (C)
unnamed: D19.2 (A2), Q11.3 (C)
unnamed: D19.3 (K1), Q12.3 (C)
unnamed: D61.2 (A2), Q13.3 (C)
unnamed: D61.3 (K1), Q14.3 (C)
unnamed: D64.2 (A2), Q15.3 (C)
unnamed: D64.3 (K1), Q16.3 (C)
unnamed: D67.2 (A2), Q17.3 (C)
unnamed: D67.3 (K1), Q18.3 (C)
unnamed: D70.2 (A2), Q19.3 (C)
unnamed: D70.3 (K1), Q20.3 (C)
unnamed: D73.2 (A2), Q21.3 (C)
unnamed: D73.3 (K1), Q22.3 (C)
unnamed: D76.2 (A2), Q23.3 (C)
unnamed: D76.3 (K1), Q24.3 (C)
unnamed: D79.2 (A2), Q25.3 (C)
unnamed: D79.3 (K1), Q26.3 (C)
unnamed: D82.2 (A2), Q27.3 (C)
unnamed: D82.3 (K1), Q28.3 (C)
unnamed: D85.2 (A2), Q29.3 (C)
unnamed: D85.3 (K1), Q30.3 (C)
unnamed: D88.2 (A2), Q31.3 (C)
unnamed: D88.3 (K1), Q32.3 (C)
unnamed: D91.2 (A2), Q33.3 (C)
unnamed: D91.3 (K1), Q34.3 (C)
unnamed: J4.T, R9.2
unnamed: J5.T, R12.2
unnamed: J6.T, R15.2
unnamed: J7.T, R18.2
unnamed: J8.T, R21.2
unnamed: J9.T, R24.2
unnamed: J10.T, R27.2
unnamed: J12.T, R30.2
unnamed: J13.T, R33.2
unnamed: J14.T, R36.2
unnamed: J15.T, R39.2
unnamed: J16.T, R42.2
unnamed: J17.T, R45.2
unnamed: J18.T, R48.2
unnamed: J19.T, R51.2
unnamed: Q5.2 (E), R7.2
unnamed: Q6.2 (E), R8.1
unnamed: Q7.2 (E), R10.2
unnamed: Q8.2 (E), R11.1
unnamed: Q9.2 (E), R13.2
unnamed: Q10.2 (E), R14.1
unnamed: Q11.2 (E), R16.2
unnamed: Q12.2 (E), R17.1
unnamed: Q13.2 (E), R19.2
unnamed: Q14.2 (E), R20.1
unnamed: Q15.2 (E), R22.2
unnamed: Q16.2 (E), R23.1
unnamed: Q17.2 (E), R25.2
unnamed: Q18.2 (E), R26.1
unnamed: Q19.2 (E), R28.2
unnamed: Q20.2 (E), R29.1
unnamed: Q21.2 (E), R31.2
unnamed: Q22.2 (E), R32.1
unnamed: Q23.2 (E), R34.2
unnamed: Q24.2 (E), R35.1
unnamed: Q25.2 (E), R37.2
unnamed: Q26.2 (E), R38.1
unnamed: Q27.2 (E), R40.2
unnamed: Q28.2 (E), R41.1
unnamed: Q29.2 (E), R43.2
unnamed: Q30.2 (E), R44.1
unnamed: Q31.2 (E), R46.2
unnamed: Q32.2 (E), R47.1
unnamed: Q33.2 (E), R49.2
unnamed: Q34.2 (E), R50.1

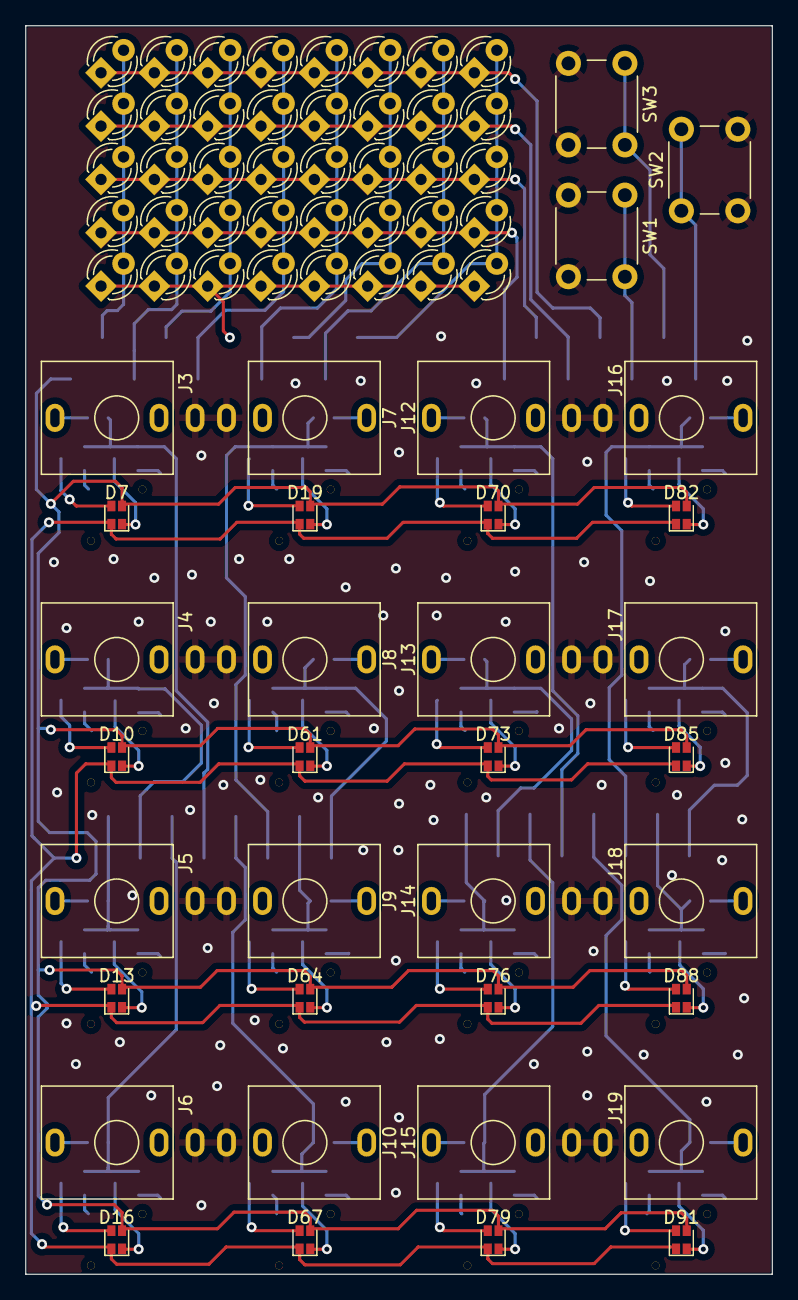
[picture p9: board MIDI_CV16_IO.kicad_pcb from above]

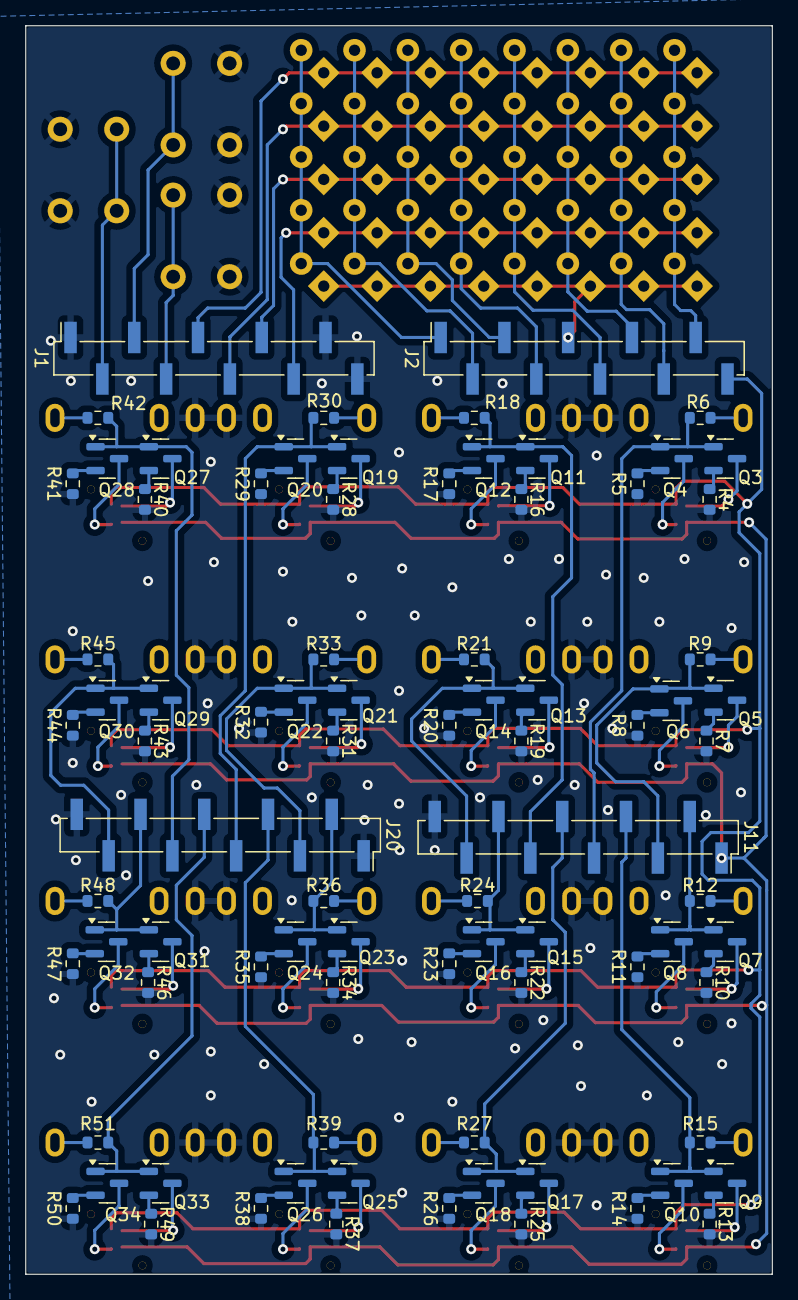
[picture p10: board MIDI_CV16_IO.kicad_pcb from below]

Board: 2 copper layers, 59.5 x 99.5 mm, 175 parts (84 on the bottom side), 115 nets.

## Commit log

2022-02-17 Update termination circuit
    [MIDI_CV16.sch]
2022-02-18 Add custom symbols and footprints
    [HI.sch, MIDI_CV16.sch, MIDI_CV16_Front.sch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]
2022-02-18 Fix DRC errors
    [MIDI_CV16.kicad_pcb, MIDI_CV16_Front.kicad_pcb, MIDI_CV16_IO.kicad_pcb]
2023-04-08 Update front panel
    [MIDI_CV16_Front.kicad_pcb, MIDI_CV16_Front.kicad_sch, MIDI_CV16_Front.sch]
2023-04-19 Update to KiCAD 7
    [HI.kicad_sch, HI.sch, MIDI_CV16.kicad_pcb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]
2023-05-07 Update PCBs to V3.0
    [HI.kicad_sch, MIDI_CV16.kicad_pcb, MIDI_CV16.kicad_sch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]
2023-05-07 Fix front panel DRC
    [MIDI_CV16_Front.kicad_pcb, MIDI_CV16_Front.kicad_sch]
2023-05-07 Maybe actually fix drc
    [MIDI_CV16_Front.kicad_pcb, MIDI_CV16_Front.kicad_sch]
2023-05-07 Fix net-tie attributes
    [MIDI_CV16.kicad_pcb]
2023-05-10 Minor fixes
    [HI.kicad_sch, MIDI_CV16.kicad_pcb, MIDI_CV16.kicad_sch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]
2023-05-11 Shrink crystal fp and add silkscreen text
    [MIDI_CV16.kicad_pcb, MIDI_CV16.kicad_sch]
2023-05-11 Consolidate resistor values
    [HI.kicad_sch, MIDI_CV16.kicad_pcb]
2023-05-14 Improve USB impedance and power headroom
    [MIDI_CV16.kicad_pcb, Powah.kicad_sch]
2023-07-09 Change CAN tranceiver to MCP2562
    [MIDI_CV16.kicad_pcb, MIDI_CV16.kicad_sch]
2023-07-09 Fix 2x8 header footprint
    [MIDI_CV16.kicad_pcb]
2023-07-09 Fix crystal footprint
    [MIDI_CV16.kicad_pcb]
2023-07-09 Fix DRC warnings
    [MIDI_CV16.kicad_pcb]
2023-07-09 Fix more drc warnings........
    [MIDI_CV16.kicad_pcb, MIDI_CV16_IO.kicad_pcb]
2023-09-01 Finalize module
    [HI.kicad_sch, MIDI_CV16.kicad_pcb, MIDI_CV16.kicad_sch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]
2024-03-30 Add message about peak-detectors on IO leds
    [outputs.kicad_sch]
2024-03-30 Remove IO peak-detectors
    [MIDI_CV16_IO.kicad_pcb, MIDI_CV16_IO.kicad_sch, outputs.kicad_sch]
2024-03-31 Switch from CC LICENSE to CERN open hardware license
2024-06-11 Specify dielectric type of SnH caps
    [Outputs.kicad_sch]
2024-06-12 Change SPI bus for EEPROM
    [HI.kicad_sch, MIDI_CV16.kicad_sch, Outputs.kicad_sch]
2024-06-12 Increase SnH capacitance
    [Outputs.kicad_sch]
2024-06-16 Layout v3.1
    [HI.kicad_sch, MIDI_CV16.kicad_pcb, MIDI_CV16.kicad_sch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]
2024-06-16 Add drc filter to kibot
2024-06-16 Add error number in kibot filter
2024-06-16 Update to kicad 8
    [HI.kicad_sch, MIDI_CV16.kicad_pcb, MIDI_CV16.kicad_sch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]
